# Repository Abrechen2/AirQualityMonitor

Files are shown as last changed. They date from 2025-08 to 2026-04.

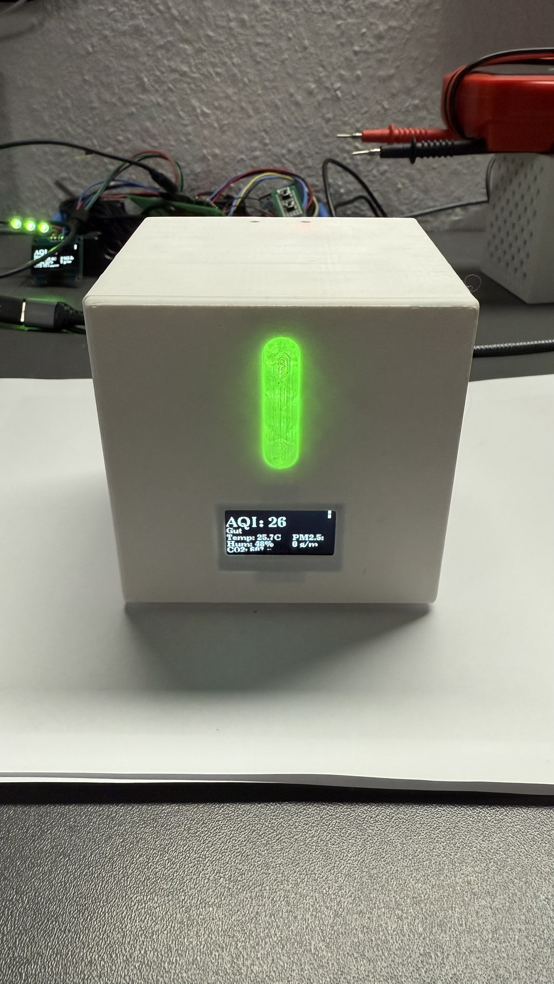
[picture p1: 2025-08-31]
Pictures/IMG_7561.JPEG

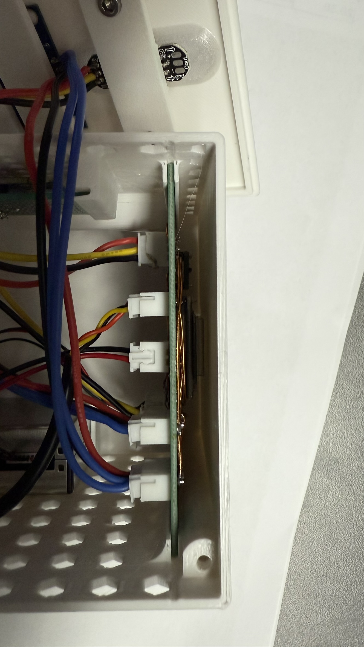
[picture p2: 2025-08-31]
Pictures/IMG_7567.JPEG

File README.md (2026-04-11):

# ESP32 Air Quality Monitor v1.5.6

   

Enclosure on Printables: <https://www.printables.com/model/1400485-esp32-air-quality-monitor-beluftetes-sensorgehause>

An advanced air-quality sensor based on the ESP32-WROOM-32 with three precise sensors for comprehensive environmental monitoring.

## Overview

This project implements a complete air-quality monitoring station with:
- **Real CO2 and TVOC values** (calculated with BME680/BME688 + BSEC)
- **Particulate matter measurement** (PM1.0, PM2.5, PM10)
- **Precise temperature measurement** via external DS18B20
- **MQTT Home Assistant integration** with automatic discovery (50+ entities)
- **Internal AQI calculation** (no external dependencies)
- **OLED display** for local visualization with 5 views
- **RGB LED status indicator** with smooth color transitions
- **Stealth mode** (display and LED off)

## Hardware Components

### Main Board
- **ESP32-WROOM-32** – microcontroller with Wi-Fi

### Sensors
| Sensor | Interface | Pin | Measurements |
|---|---|-----|---|
| **BME680/BME688** | I2C | SDA=21, SCL=22 | Temperature, humidity, pressure, gas resistance, IAQ, CO2eq, TVOC |
| **PMS5003** | UART | RX=16, TX=17 | PM1.0, PM2.5, PM10 µg/m³ |
| **DS18B20** | 1-Wire | GPIO27 | External temperature (±0.5 °C) |

### Output Devices
| Component | Interface | Pin |
|---|---|-----|
| **SH1106 OLED** (128×64) | I2C | SDA=21, SCL=22 |
| **WS2812B RGB LEDs** (3x) | GPIO | GPIO5 |
| **Button** | GPIO | GPIO33 |

## Key Features

### BSEC Algorithm Integration
- **Bosch BSEC library** (LP mode, 3s interval) for precise air-quality measurement
- **IAQ index** (Indoor Air Quality, 0-500)
- **CO2 equivalent** and **TVOC equivalent** calculation
- **Adaptive calibration** — state persisted to EEPROM every 6 hours

### MQTT Home Assistant Integration
- **Automatic device discovery** via MQTT discovery protocol
- **50+ sensor entities** including calculated values, alerts, and system status
- **Real-time updates** every 10 seconds
- **Wi-Fi auto-reconnect** with fallback modes
- **All calculations performed on ESP32** — no external dependencies
- **`has_entity_name: true`** + `object_id` for clean, predictable entity IDs

### OLED Display Views
| View | Content |
|---|---|
| OVERVIEW | AQI, level, temperature, humidity, CO2, PM2.5 |
| ENVIRONMENT | DS18B20 temp, BME68X temp/humidity/pressure |
| PARTICLES | PM1.0, PM2.5, PM10, AQI |
| GAS | IAQ, static IAQ, CO2, VOC, gas resistance, calibration |
| SYSTEM | Uptime, WiFi, IP, sensor count, firmware version |

### LED Status Colors
| Color | IAQ Range | Meaning |
|---|---|---|
| Green | 0-50 | Excellent |
| Yellow | 51-100 | Good |
| Orange | 101-150 | Lightly polluted |
| Red | 151-200 | Moderately polluted |
| Purple | 201-300 | Heavily polluted |
| Dark red | 300+ | Severely polluted |

## Installation

### 1. Hardware Connections
```
BME680/688:  SDA → GPIO21, SCL → GPIO22 (addr 0x76 or 0x77)
PMS5003:     RX → GPIO16, TX → GPIO17
DS18B20:     Data → GPIO27 (with 4.7kΩ pull-up)
OLED:        SDA → GPIO21, SCL → GPIO22 (addr 0x3C)
LEDs:        Data → GPIO5
Button:      GPIO33 (internal pull-up)
```

### 2. Required Libraries
- BSEC Software Library (Bosch Sensortec)
- PMS (PMS5003 sensor)
- DallasTemperature + OneWire (DS18B20)
- U8g2lib (OLED display)
- Adafruit NeoPixel (WS2812B LEDs)
- ArduinoJson
- PubSubClient (MQTT)
- ArduinoOTA

### 3. Arduino IDE Board Settings

These are the verified-working settings for the Arduino IDE (Tools menu) when
flashing an ESP32-WROOM-32 board with this firmware:

| Setting | Value |
|---|---|
| Board | ESP32 Dev Module |
| CPU Frequency | 240 MHz (WiFi/BT) |
| Core Debug Level | None |
| Erase All Flash Before Sketch Upload | Disabled |
| Events Run On | Core 1 |
| Flash Frequency | 80 MHz |
| Flash Mode | QIO |
| Flash Size | 4 MB (32 Mb) |
| JTAG Adapter | Disabled |
| Arduino Runs On | Core 1 |
| Partition Scheme | Default 4 MB with spiffs (1.2 MB APP / 1.5 MB SPIFFS) |
| PSRAM | Disabled |
| Upload Speed | 115200 |
| Zigbee Mode | Disabled |

> **Note on Partition Scheme:** The Arduino IDE GUI uses "Default" (1.2 MB APP
> slots). The `arduino-cli` OTA compile command in `CLAUDE.md` instead uses
> `min_spiffs` (1.9 MB APP slots) for more headroom as the firmware approaches
> 85 % of the flash (~1.1 MB). Both work, as long as the binary fits the OTA
> slot. For the initial USB flash, "Default" is fine.

### 4. Configuration

Create `secrets.h` from the template:
```bash
cp secrets_template.h secrets.h
```

Fill in credentials:
```cpp
#define WIFI_SSID       "YOUR_SSID"
#define WIFI_PASSWORD   "YOUR_PASSWORD"
#define MQTT_BROKER_HOST "192.168.1.100"
#define MQTT_BROKER_PORT 1883
#define HOSTNAME        "ENV-Room_Name"
#define MQTT_TOPIC      "ENV-Room_Name"   // must match HOSTNAME
#define OTA_PASSWORD    "yourpassword"
```

### 5. Compile and Flash

**Compile:**
```bash
ARDUINO_CLI="C:/Program Files/Arduino IDE/resources/app/lib/backend/resources/arduino-cli.exe"
"$ARDUINO_CLI" compile --fqbn esp32:esp32:esp32 \
  --build-property "build.partitions=min_spiffs" \
  --build-property "upload.maximum_size=1966080" \
  ./
```

**OTA Flash:**
```bash
ESPOTA="C:/Users/.../Arduino15/packages/esp32/hardware/esp32/3.3.7/tools/espota.py"
python "$ESPOTA" -i <DEVICE_IP> -p 3232 --auth="<OTA_PASSWORD>" \
  -f ./build/AirQualityMonitor.ino.bin
```

### 6. Calibration
- **BME680/688**: automatic BSEC calibration, accurate after 24-48h
- **State persistence** in EEPROM every 6 hours (survives power cycles)
- **CO2/TVOC accuracy** improves over 4-7 days of continuous operation

## MQTT Data Format

### Topics
| Topic | Description |
|---|---|
| `tele/<HOSTNAME>/state` | JSON payload, published every 10s |
| `tele/<HOSTNAME>/LWT` | `Online` / `Offline` (retained) |
| `homeassistant/<domain>/airqualitymonitor_<MAC>_<field>/config` | Discovery configs (retained) |

### Example State Payload
```json
{
  "temperature": 21.45,
  "humidity": 48.2,
  "pressure": 956.3,
  "iaq": 51,
  "static_iaq": 49,
  "iaq_accuracy": 3,
  "static_iaq_accuracy": 3,
  "co2": 621,
  "co2_accuracy": 3,
  "voc": 0.52,
  "voc_accuracy": 3,
  "gas_resistance": 183420,
  "bsec_calibrated": 1,
  "tvoc_ppb": 520,
  "tvoc_mgm3": 0.52,
  "pm1_0": 2,
  "pm2_5": 4,
  "pm10": 5,
  "dew_point": 10.1,
  "heat_index": 21.3,
  "absolute_humidity": 8.74,
  "comfort_index": 72,
  "external_temperature": 22.06,
  "aqi_index": 26.4,
  "aqi_category": 0,
  "pm2_5_aqi": 16,
  "pm10_aqi": 4,
  "iaq_aqi": 26,
  "sensor_bme68x_available": 1,
  "sensor_ds18b20_available": 1,
  "sensor_pms5003_available": 1,
  "sensors_available_count": 3,
  "sensor_reliable": 1,
  "bme68x_stable": 1,
  "bme68x_runin_complete": 1,
  "wifi_rssi": -62,
  "wifi_connected": 1,
  "mqtt_connected": 1,
  "stealth_mode": 0,
  "display_enabled": 1,
  "current_view": 0,
  "uptime": 14523,
  "free_heap": 148320,
  "ip_address": "192.168.200.78",
  "alert_aqi": 0,
  "alert_co2": 0,
  "alert_pm25": 0,
  "alert_tvoc": 0,
  "alert_humidity_low": 0,
  "alert_humidity_high": 0,
  "ventilation_needed": 0
}
```

### Home Assistant Entities
The device publishes discovery configs for all sensors automatically. Entity IDs follow the pattern `<domain>.env_<room>_<field>`.

**Environmental:**
`temperature`, `humidity`, `pressure`, `external_temperature`, `dew_point`, `heat_index`, `absolute_humidity`

**Air Quality (BSEC):**
`iaq`, `static_iaq`, `co2`, `voc`, `tvoc_mgm3`, `tvoc_ppb`, `gas_resistance`, accuracy indicators

**Particulate Matter:**
`pm1_0`, `pm2_5`, `pm10`, `pm2_5_aqi`, `pm10_aqi`

**AQI:**
`aqi_index`, `aqi_category`, `iaq_aqi`

**Comfort:**
`comfort_index`

**System:**
`uptime`, `free_heap`, `wifi_rssi`, `ip_address`, `current_view`, `sensors_available_count`

**Binary sensors:**
`sensor_bme68x_available`, `sensor_ds18b20_available`, `sensor_pms5003_available`, `bsec_calibrated`, `sensor_reliable`, `bme68x_stable`, `bme68x_runin_complete`, `wifi_connected`, `mqtt_connected`, `stealth_mode`, `display_enabled`

**Alerts:**
`alert_aqi`, `alert_co2`, `alert_pm25`, `alert_tvoc`, `alert_humidity_low`, `alert_humidity_high`, `ventilation_needed`

## Debugging

Serial debug output is controlled via `DEBUG_ENABLED` in `config.h`. Macros `DEBUG_INFO`, `DEBUG_WARN`, and `DEBUG_ERROR` provide formatted logs.

## Schematics & Layout

All KiCad files are in the [Schematics](Schematics) directory:
- [MainPCB-Schematic.pdf](Schematics/MainPCB-Schematic.pdf)
- [MainPCB-Layout.pdf](Schematics/MainPCB-Layout.pdf)

## Project Structure

```
AirQualityMonitor/
├── AirQualityMonitor.ino    # Main program
├── config.h                 # Hardware and timing configuration
├── secrets.h                # Credentials (not tracked in git)
├── secrets_template.h       # Template for secrets.h
├── SensorManager.h          # BME680/688, DS18B20, PMS5003 management
├── DisplayManager.h         # SH1106 OLED display and NeoPixel LEDs
├── ButtonHandler.h          # Button handling (view switch, stealth toggle)
├── LEDManager.h             # RGB LED control with smooth transitions
├── WiFiManager.h            # WiFi connection and reconnect logic
├── MQTTManager.h            # MQTT, Home Assistant discovery, data publish
├── Calculations.h           # AQI, comfort, dew point, heat index
├── TimeUtils.h              # Uptime helpers
├── DATENPUNKTE.md           # Detailed data point documentation (German)
├── CLAUDE.md                # Device inventory and OTA procedure
├── Schematics/              # KiCad project and PDFs
├── Printdata/               # STL and STEP files for enclosure
├── Pictures/                # Photos of the device
├── LICENSE                  # MIT license
└── README.md                # This file
```

## Troubleshooting

### Wi-Fi Connection Issues
- Check SSID and password in `secrets.h`
- 2.4 GHz only — 5 GHz not supported by ESP32-WROOM-32
- Verify signal strength (`wifi_rssi` entity in HA)

### Sensor Not Detected
- Check I2C connections (SDA=21, SCL=22)
- BME680/688: address must be 0x76 or 0x77 — system auto-detects both
- PMS5003: check UART wiring (RX/TX crossed), verify 5V power supply

### BSEC Calibration
| Phase | iaq_accuracy | Time |
|---|---|---|
| Warm-up | 0 | First 5 min |
| Initial calibration | 1 | 5-30 min |
| Calibrating | 2 | Up to 24h |
| Fully calibrated | 3 | After 4-7 days |

State is saved to EEPROM on first accuracy=2 and every 6h thereafter. After power cycle, calibration resumes quickly from saved state.

### OTA Flash Fails ("No response from device")
- Verify OTA password matches `OTA_PASSWORD` in `secrets.h`
- OTA port 3232 must be reachable from same VLAN
- Ensure `secrets.h` has the correct `HOSTNAME` for the target device before compiling
- See `CLAUDE.md` for the full sequential flash procedure

## Version History

| Version | Changes |
|---|---|
| **v1.5.6** | Stealth-mode button now shows a 3-2-1 countdown overlay while held and fires the toggle at 3s (no more "release-and-hope"); **critical fix**: `MQTTManager::init()` now re-reads hostname from `ConfigManager` after EEPROM load, so the same binary can be flashed to all boards without publishing under the wrong topic |
| **v1.5.5** | Sensible MQTT decimal precision; `has_entity_name` + `object_id` for clean HA entity IDs; all fields always published; `aqi_color_code` removed; firmware version on OLED |
| **v1.5.4** | MAC read after WiFi init (fixes discovery MAC mismatch); unique MQTT client ID per device |
| **v1.5.3** | BSEC state persistence to EEPROM; config EEPROM storage |
| **v1.5.2** | `expire_after` in MQTT discovery |
| **v1.5.1** | Fix MAC read before WiFi init returning `00ff00000000` |
| **v1.2.0** | MQTT Home Assistant integration; internal AQI calculation; removed Node-RED dependency |
| **v1.1.0** | Switch BSEC from ULP to LP mode for reliable CO2/VOC output |
| **v1.0.0** | Initial release |

## Contributing

1. Fork the repository
2. Create a feature branch
3. Commit your changes
4. Open a pull request

## Author

**Abrechen2**

## License

MIT License — see [LICENSE](LICENSE) for details.

---

*For detailed data point documentation see [DATENPUNKTE.md](DATENPUNKTE.md)*

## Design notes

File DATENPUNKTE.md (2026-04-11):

# Datenpunkte Erklaerung - ESP32 Luftqualitaetssensor

Diese Dokumentation erklaert alle vom Sensor erfassten und berechneten Datenpunkte,
deren Bedeutung, Quelle und Praezision im MQTT-State-Topic.

**MQTT State-Topic:** `tele/<HOSTNAME>/state`  
**Aktualisierungsintervall:** 10 Sekunden

---

## BME680 / BME688 Sensor (via BSEC LP-Mode)

### Basis-Umweltdaten

#### `temperature` — BME68X Temperatur
- **Typ:** float, 2 Dezimalstellen (°C)
- **Bereich:** -40 bis +85 °C
- **Quelle:** BSEC-kompensiert (Selbsterwärmungskorrektur integriert) + Software-Offset (`DEFAULT_TEMP_CORRECTION`)
- **Hinweis:** Für absolute Raumtemperatur DS18B20 verwenden (`external_temperature`)

#### `humidity` — Luftfeuchtigkeit
- **Typ:** float, 1 Dezimalstelle (% rH)
- **Bereich:** 0–100 %
- **Genauigkeit:** ±3 % rH (20–80 % rH)
- **Quelle:** BME68X via BSEC, mit Software-Offset (`DEFAULT_HUMIDITY_CORRECTION`)

#### `pressure` — Luftdruck
- **Typ:** float, 1 Dezimalstelle (hPa)
- **Bereich:** 300–1100 hPa
- **Genauigkeit:** ±1.0 hPa
- **Quelle:** BME68X Rohwert (Pa → hPa)

#### `gas_resistance` — Gaswiderstand
- **Typ:** integer (Ω)
- **Bereich:** ~10.000–500.000 Ω
- **Bedeutung:** Rohdaten des MOX-Gassensors. Niedriger Wert = schlechtere Luftqualität / mehr flüchtige organische Verbindungen
- **Hinweis:** Nicht direkt interpretierbar — BSEC verarbeitet diesen Wert intern

### BSEC-Algorithmus Outputs

#### `iaq` — Indoor Air Quality
- **Typ:** integer (0–500)
- **Quelle:** Proprietärer Bosch BSEC Algorithmus (Gaswiderstand, Temperatur, Luftfeuchtigkeit)
- **Kalibrierung:** Verbessert sich über 4–7 Tage; State wird alle 6h in EEPROM gespeichert

| Wert | Bewertung |
|---|---|
| 0–50 | Excellent |
| 51–100 | Good |
| 101–150 | Lightly Polluted |
| 151–200 | Moderately Polluted |
| 201–300 | Heavily Polluted |
| 300+ | Severely Polluted |

#### `static_iaq` — Static IAQ
- **Typ:** integer (0–500)
- **Unterschied zu IAQ:** Weniger empfindlich gegenüber kurzfristigen Änderungen, besser für Langzeittrend

#### `iaq_accuracy` / `static_iaq_accuracy` — Kalibrierungsfortschritt
- **Typ:** integer (0–3)

| Wert | Bedeutung |
|---|---|
| 0 | Sensor läuft ein (erste ~5 min) |
| 1 | Unsichere Kalibrierung |
| 2 | Kalibrierung aktiv (~24h) |
| 3 | Vollständig kalibriert (4–7 Tage) |

#### `co2` — CO₂-Äquivalent
- **Typ:** integer (ppm)
- **Bereich:** 400–40.000 ppm
- **Wichtig:** Nicht direkt gemessen — BSEC-Schätzung auf Basis des Gaswiderstandsverlaufs

| Wert | Bewertung |
|---|---|
| 400–1000 ppm | Gut |
| 1000–2000 ppm | Akzeptabel |
| 2000–5000 ppm | Schlecht |
| >5000 ppm | Gesundheitsschädlich |

#### `co2_accuracy` — CO₂ Genauigkeitsstatus
- **Typ:** integer (0–3), wie `iaq_accuracy`

#### `voc` / `tvoc_mgm3` — TVOC-Äquivalent
- **Typ:** float, 2 Dezimalstellen (mg/m³)
- **Bereich:** 0–60 mg/m³
- **Vollname:** Total Volatile Organic Compounds
- **Quelle:** BSEC-Algorithmus (Gaswiderstandsverlauf)
- **Hinweis:** Relative Werte, keine absoluten Konzentrationen einzelner Substanzen

| Wert | Bewertung |
|---|---|
| 0–0.3 mg/m³ | Excellent |
| 0.3–1.0 mg/m³ | Good |
| 1.0–3.0 mg/m³ | Moderate |
| 3.0–25 mg/m³ | Poor |
| >25 mg/m³ | Unhealthy |

#### `tvoc_ppb` — TVOC in ppb
- **Typ:** integer (ppb)
- **Berechnung:** `voc_mgm3 * 1000`
- **Verwendung:** Für HA-Karten die ppb bevorzugen

#### `voc_accuracy` — VOC Genauigkeitsstatus
- **Typ:** integer (0–3)

#### `bsec_calibrated` — Kalibrierungsstatus
- **Typ:** binary (0/1)
- **Wert 1:** `iaqAccuracy >= 1`

---

## DS18B20 Temperatursensor

#### `external_temperature` — Externe Temperatur
- **Typ:** float, 2 Dezimalstellen (°C)
- **Bereich:** -55 bis +125 °C
- **Genauigkeit:** ±0.5 °C (-10 bis +85 °C)
- **Auflösung:** 12-bit (0.0625 °C)
- **Verwendung:** Primäre Raumtemperatur (kein Selbsterwärmungseffekt)
- **Leseintervall:** 10 Sekunden

---

## PMS5003 Feinstaubsensor

Messprinzip: Laser-Streulicht — Partikel werden gezählt und in Massenkonzentration umgerechnet.

#### `pm1_0` — PM1.0
- **Typ:** integer (µg/m³)
- **Definition:** Partikel mit Durchmesser ≤ 1.0 µm
- **Gesundheit:** Dringen bis in Lungenbläschen vor

#### `pm2_5` — PM2.5
- **Typ:** integer (µg/m³)
- **Definition:** Partikel ≤ 2.5 µm

| WHO-Grenzwert | Wert |
|---|---|
| Jahresmittel | 5 µg/m³ |
| 24h-Mittel | 15 µg/m³ |

#### `pm10` — PM10
- **Typ:** integer (µg/m³)
- **Definition:** Partikel ≤ 10 µm

| WHO-Grenzwert | Wert |
|---|---|
| Jahresmittel | 15 µg/m³ |
| 24h-Mittel | 45 µg/m³ |

---

## Berechnete Komfortwerte (intern auf ESP32)

#### `dew_point` — Taupunkt
- **Typ:** float, 1 Dezimalstelle (°C)
- **Berechnung:** Magnus-Formel aus Temperatur + Luftfeuchtigkeit
- **Bedeutung:** Unter diesem Wert kondensiert Wasserdampf

#### `heat_index` — Gefühlte Temperatur
- **Typ:** float, 1 Dezimalstelle (°C)
- **Berechnung:** Rothfusz-Regression (Temperatur + Luftfeuchtigkeit)
- **Bedeutung:** Relevanter über 27 °C bei hoher Luftfeuchtigkeit

#### `absolute_humidity` — Absolute Luftfeuchtigkeit
- **Typ:** float, 2 Dezimalstellen (g/m³)
- **Berechnung:** Aus Temperatur und relativer Luftfeuchtigkeit
- **Verwendung:** Lüftungssteuerung (innen vs. außen vergleichen)

#### `comfort_index` — Komfortindex
- **Typ:** integer (0–100)
- **Berechnung:** Kombiniert Temperatur, Luftfeuchtigkeit und Heat Index
- **100:** Optimaler Komfort; niedrigere Werte = zu warm/kalt/trocken/feucht

---

## AQI-Werte (intern berechnet)

#### `aqi_index` — Gesamt-AQI
- **Typ:** float, 1 Dezimalstelle
- **Berechnung:** Gewichtete Kombination aus PM2.5-AQI, PM10-AQI, IAQ-AQI
- **Grundlage:** US-EPA AQI Skala

#### `aqi_category` — AQI Kategorie
- **Typ:** integer (0–5)

| Wert | Bedeutung |
|---|---|
| 0 | Good (0–50) |
| 1 | Moderate (51–100) |
| 2 | Unhealthy for Sensitive Groups (101–150) |
| 3 | Unhealthy (151–200) |
| 4 | Very Unhealthy (201–300) |
| 5 | Hazardous (300+) |

#### `pm2_5_aqi` — PM2.5 AQI
- **Typ:** integer
- **Berechnung:** US-EPA Breakpoint-Tabelle für PM2.5

#### `pm10_aqi` — PM10 AQI
- **Typ:** integer
- **Berechnung:** US-EPA Breakpoint-Tabelle für PM10

#### `iaq_aqi` — IAQ → AQI Umrechnung
- **Typ:** integer
- **Berechnung:** Lineares Mapping von BSEC IAQ (0–500) auf AQI Skala

---

## Alert-Flags (Binary Sensors)

Alle Flags: integer 0 oder 1

| Feld | Auslöser |
|---|---|
| `alert_aqi` | AQI > 100 (Unhealthy for Sensitive Groups) |
| `alert_co2` | CO₂ > 1500 ppm |
| `alert_pm25` | PM2.5 > 35 µg/m³ |
| `alert_tvoc` | TVOC > 1.0 mg/m³ |
| `alert_humidity_low` | Luftfeuchtigkeit < 30 % |
| `alert_humidity_high` | Luftfeuchtigkeit > 70 % |
| `ventilation_needed` | Kombination aus CO₂ oder TVOC-Alert |

---

## Sensor-Verfügbarkeit (Binary Sensors)

| Feld | Bedeutung |
|---|---|
| `sensor_bme68x_available` | BME680/688 initialisiert und liefert Daten |
| `sensor_ds18b20_available` | DS18B20 gefunden und liest Temperatur |
| `sensor_pms5003_available` | PMS5003 kommuniziert (0 nach 5 Fehler in Folge) |
| `bsec_calibrated` | iaqAccuracy >= 1 |
| `sensor_reliable` | Mindestens ein Sensor liefert valide Daten |
| `bme68x_stable` | iaqAccuracy >= 2 |
| `bme68x_runin_complete` | iaqAccuracy >= 3 (vollständig kalibriert) |
| `sensors_available_count` | Anzahl aktiver Sensoren (0–3) |

**Wichtig:** Alle Sensor-Felder werden immer publiziert, auch wenn der Sensor offline ist (Wert = 0). `sensor_<x>_available = 0` zeigt die Nichtverfügbarkeit an.

---

## System-Status

| Feld | Typ | Bedeutung |
|---|-----|---|
| `uptime` | integer (s) | Sekunden seit letztem Reboot |
| `free_heap` | integer (Bytes) | Freier Heap-Speicher |
| `wifi_rssi` | integer (dBm) | WLAN-Signalstärke |
| `wifi_connected` | binary | WLAN verbunden |
| `mqtt_connected` | binary | MQTT-Broker verbunden |
| `ip_address` | string | Aktuelle IP-Adresse |
| `stealth_mode` | binary | Stealth-Modus aktiv (Display + LEDs aus) |
| `display_enabled` | binary | OLED erkannt und aktiv |
| `current_view` | integer (0–4) | Aktuell angezeigte View (0=Overview … 4=System) |

---

## BSEC Konfiguration

**Modus:** LP (Low Power) — 3-Sekunden-Messintervall  
**Vorteil:** Zuverlässige CO₂/VOC-Ausgaben (ULP liefert hier Nullwerte)  
**State-Speicherung:** alle 6h in EEPROM (Adresse 0); zusätzlich sofort beim Erreichen von iaqAccuracy=2

Aktive BSEC-Outputs:
```
BSEC_OUTPUT_IAQ
BSEC_OUTPUT_STATIC_IAQ
BSEC_OUTPUT_CO2_EQUIVALENT
BSEC_OUTPUT_BREATH_VOC_EQUIVALENT
BSEC_OUTPUT_SENSOR_HEAT_COMPENSATED_TEMPERATURE
BSEC_OUTPUT_SENSOR_HEAT_COMPENSATED_HUMIDITY
BSEC_OUTPUT_RAW_PRESSURE
BSEC_OUTPUT_RAW_GAS
BSEC_OUTPUT_STABILIZATION_STATUS
BSEC_OUTPUT_RUN_IN_STATUS
BSEC_OUTPUT_GAS_PERCENTAGE
```

---

## Wichtige Hinweise

- **CO₂ und TVOC sind Schätzwerte** — kein direkter Gassensor, nur BSEC-Algorithmus
- **PMS5003** ist unzuverlässig bei Luftfeuchtigkeit > 85 %
- **BME680 Selbsterwärmung** wird durch BSEC und Software-Offset (`DEFAULT_TEMP_CORRECTION = -3.5 °C`) kompensiert; DS18B20 ist die Referenztemperatur
- **Erste 24–48h nach Neuinstallation:** iaqAccuracy ≤ 1, CO₂/VOC-Werte noch unzuverlässig

---

*Dokumentiert für Firmware v1.5.5*

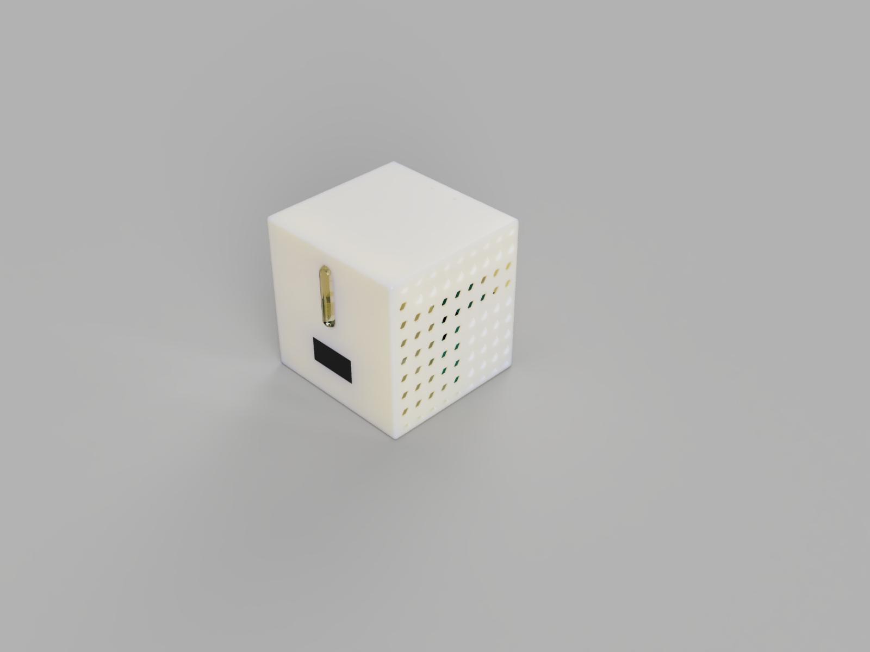
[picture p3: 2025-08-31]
Pictures/AirQualityMonitor.jpg

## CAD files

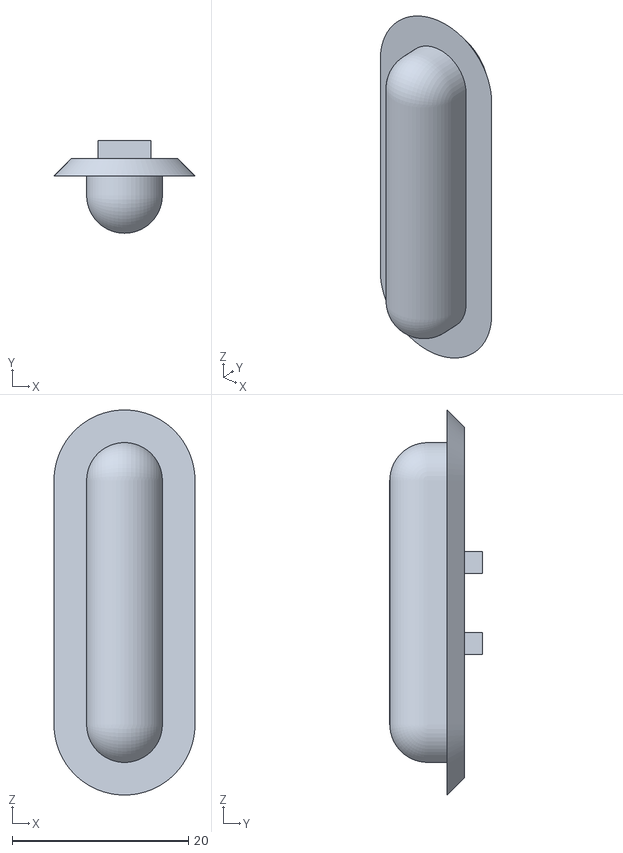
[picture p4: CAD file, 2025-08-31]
Printdata/Diffusor.stl
16.0 x 10.5 x 43.7

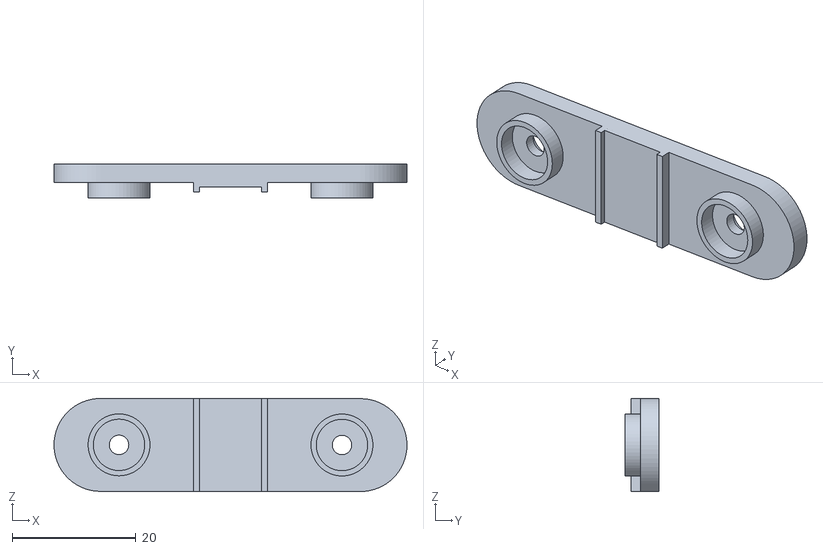
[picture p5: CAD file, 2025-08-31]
Printdata/LEDHalter.stl
57.0 x 5.50 x 15.0

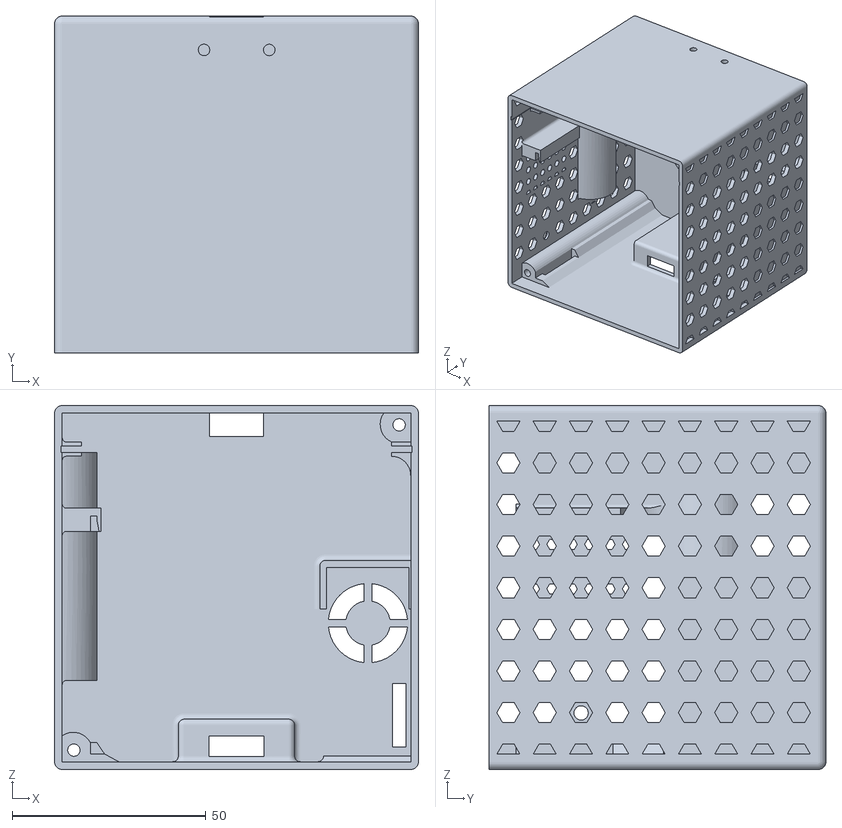
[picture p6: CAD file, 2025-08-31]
Printdata/Gehäuse.stl
94.0 x 87.0 x 94.0

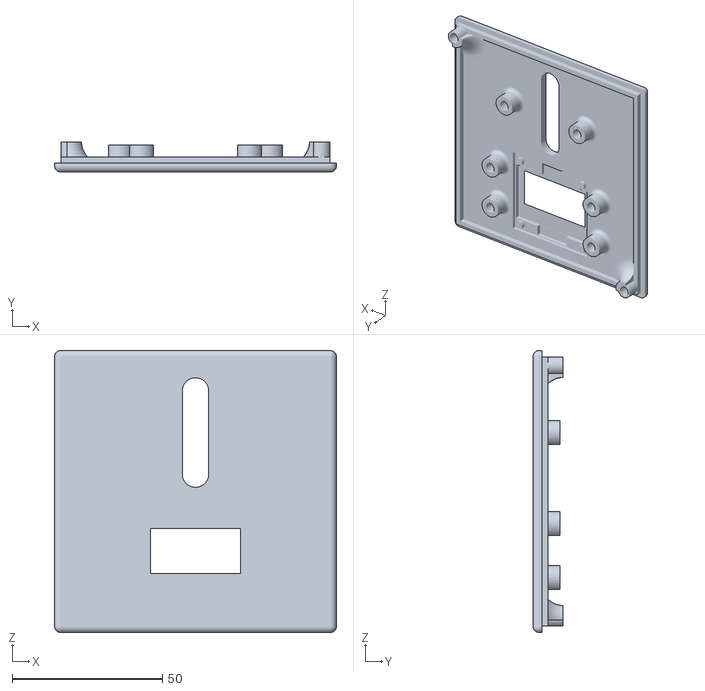
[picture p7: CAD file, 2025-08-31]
Printdata/Deckel.stl
94.0 x 10.0 x 94.0

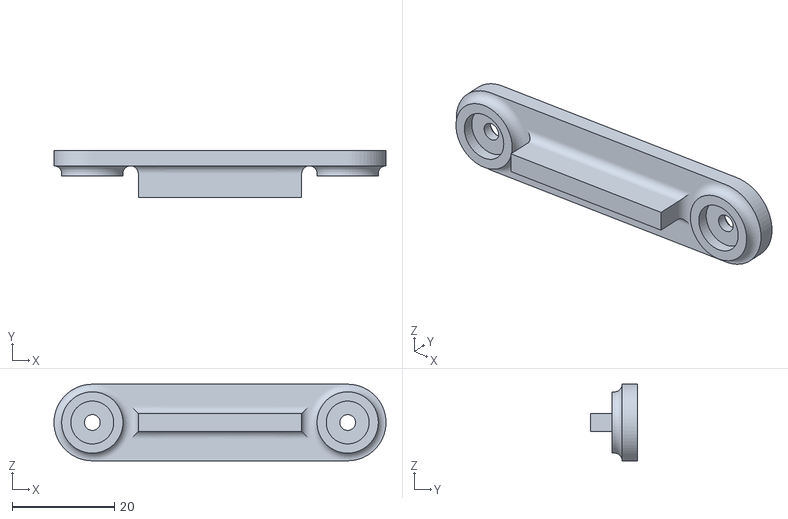
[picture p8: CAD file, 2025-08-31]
Printdata/OledHalter.stl
65.0 x 9.17 x 15.0

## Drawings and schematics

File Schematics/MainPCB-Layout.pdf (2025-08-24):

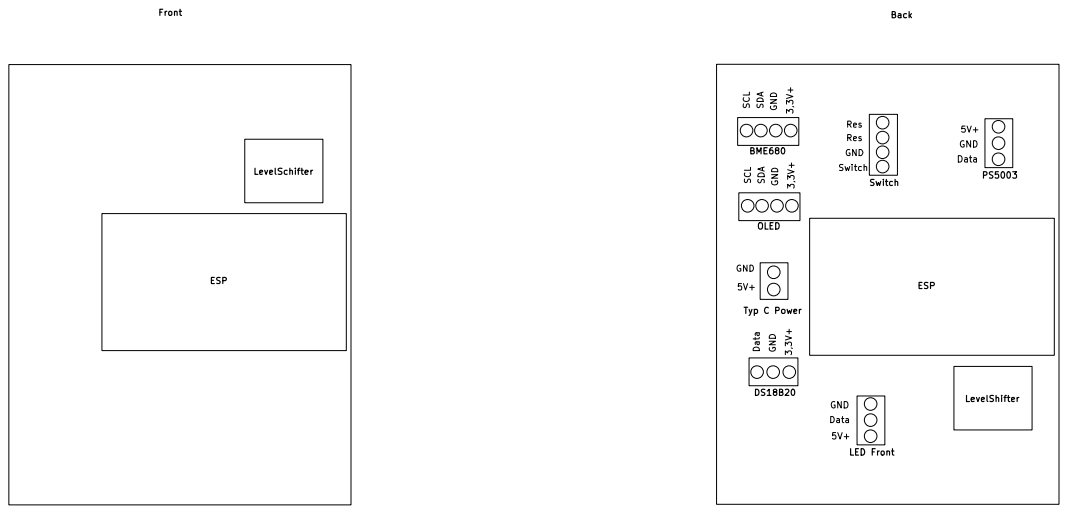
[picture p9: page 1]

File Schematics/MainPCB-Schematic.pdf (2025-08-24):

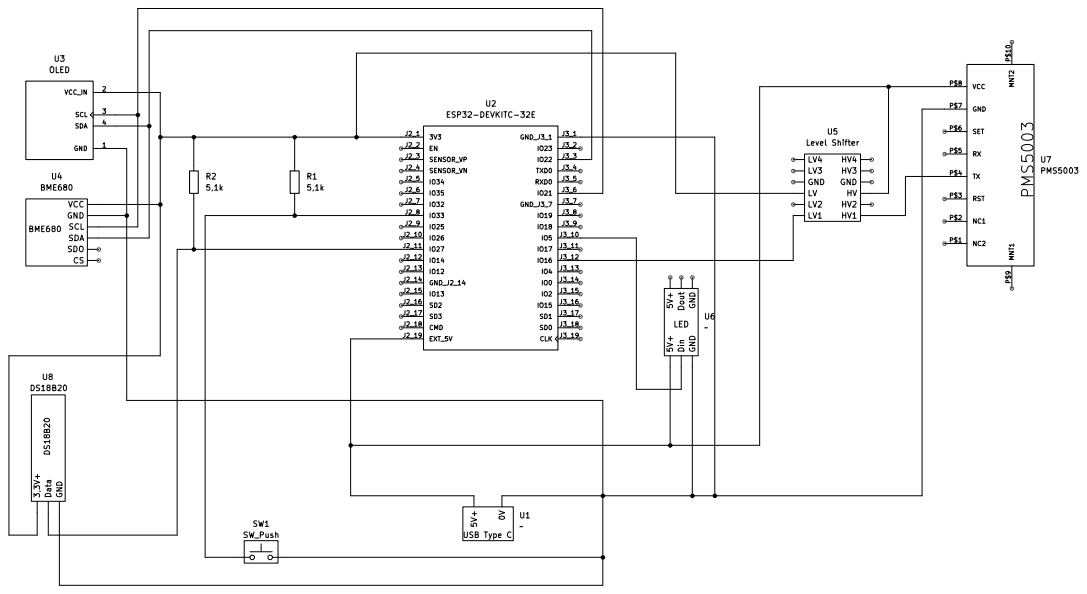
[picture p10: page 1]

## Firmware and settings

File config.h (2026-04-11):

#ifndef CONFIG_H
#define CONFIG_H

// ===== FIRMWARE VERSION =====
#define FIRMWARE_VERSION "1.5.6"

// ===== HARDWARE CONFIGURATION =====
#define LED_PIN 5
#define NUM_LEDS 3
#define LED_BRIGHTNESS_NORMAL 20
#define LED_BRIGHTNESS_STEALTH 1

// Display
#define SCREEN_WIDTH 128
#define SCREEN_HEIGHT 64
#define DISPLAY_SCL 22
#define DISPLAY_SDA 21
#define DISPLAY_CONTRAST_NORMAL 255
#define DISPLAY_CONTRAST_STEALTH 0

// Sensors
#define PMS_RX_PIN 16
#define PMS_TX_PIN 17
#define DS18B20_PIN 27  // GPIO27 (original configuration retained)

// BME680/BME688 I2C addresses (standard: 0x76 with SDO low, 0x77 with SDO high)
#ifndef BME68X_I2C_ADDR_LOW
#define BME68X_I2C_ADDR_LOW 0x76
#endif
#ifndef BME68X_I2C_ADDR_HIGH
#define BME68X_I2C_ADDR_HIGH 0x77
#endif

// Button - only use select
#define BUTTON_SELECT_PIN 33
#define BUTTON_DEBOUNCE_MS 50
#define BUTTON_LONG_PRESS_MS 3000             // 3 seconds to trigger stealth toggle
#define BUTTON_COUNTDOWN_SHOW_AFTER_MS 300    // Start showing countdown after 300ms hold

// ===== TIMING CONFIGURATION =====
#define DATA_SEND_INTERVAL 10000       // 10 seconds
#define SENSOR_READ_INTERVAL 3000      // 3 seconds (BSEC ULP mode compromise)
#define WIFI_CONNECT_TIMEOUT 8000      // 8 seconds
#define STEALTH_TEMP_ON_MS 20000       // 20 seconds temporary activation
#define LED_TRANSITION_STEPS 20        // Number of steps for smooth color transition
#define LED_TRANSITION_INTERVAL_MS 50  // Time between transition steps (ms)

// ===== MQTT CONFIGURATION =====
#define MQTT_PUBLISH_INTERVAL 10000           // 10 seconds (synchronized with DATA_SEND_INTERVAL)
#define MQTT_RECONNECT_INTERVAL 5000          // 5 seconds between reconnect attempts
#define MQTT_MAX_PACKET_SIZE 2048             // Maximum MQTT packet size (bytes)
#define DISCOVERY_REPUBLISH_INTERVAL 3600000  // 60 minutes (ms) - republish discovery config periodically

// ===== SENSOR CONFIGURATION =====
#define DEFAULT_TEMP_CORRECTION -3.5
#define DEFAULT_HUMIDITY_CORRECTION 0.0

// BSEC configuration
#define BSEC_STATE_SAVE_INTERVAL 21600000  // 6 hours in ms
#define BSEC_BASELINE_EEPROM_ADDR 0

// Config storage in EEPROM (after BSEC state)
#define CONFIG_EEPROM_ADDR 512  // Start address for config storage
#define CONFIG_EEPROM_SIZE 256  // Size allocated for config (max 512 total)

// ===== VALIDATION CONSTANTS =====
// Sensor value ranges for plausibility checks
#define TEMP_MIN -40.0f       // Minimum valid temperature (°C)
#define TEMP_MAX 85.0f        // Maximum valid temperature (°C)
#define HUMIDITY_MIN 0.0f     // Minimum valid humidity (%)
#define HUMIDITY_MAX 100.0f   // Maximum valid humidity (%)
#define PRESSURE_MIN 300.0f   // Minimum valid pressure (hPa)
#define PRESSURE_MAX 1100.0f  // Maximum valid pressure (hPa)
#define IAQ_MIN 0.0f          // Minimum valid IAQ
#define IAQ_MAX 500.0f        // Maximum valid IAQ
#define CO2_MIN 400.0f        // Minimum valid CO2 (ppm)
#define CO2_MAX 40000.0f      // Maximum valid CO2 (ppm)
#define VOC_MIN 0.0f          // Minimum valid VOC (mg/m³)
#define VOC_MAX 60.0f         // Maximum valid VOC (mg/m³)
#define PM_MIN 0              // Minimum valid PM value (µg/m³)
#define PM_MAX 1000           // Maximum valid PM value (µg/m³)

// HTTP/Network constants
#define HTTP_MAX_RESPONSE_SIZE 1024  // Maximum HTTP response size (bytes)
#define HTTP_TIMEOUT_MS 5000         // HTTP request timeout (ms)
#define HTTP_AQI_TIMEOUT_MS 3000     // AQI request timeout (ms)
#define JSON_MAX_SIZE 256            // Maximum JSON document size (bytes)

// PMS5003 constants
#define PMS_READ_TIMEOUT_MS 1000  // PMS5003 read timeout (ms)
#define PMS_WAKE_TIME_MS 2000     // PMS5003 wake time (ms)
#define PMS_RETRY_COUNT 2         // Maximum retry attempts for PMS5003

// DS18B20 constants
#define DS18B20_CONVERSION_TIME_MS 750  // DS18B20 conversion time (ms)
#define DS18B20_READ_INTERVAL_MS 10000  // DS18B20 read interval (ms)

// Type conversion limits (for overflow protection)
#define INT16_TEMP_MAX 3276        // Max temp * 100 for int16_t (32.76°C)
#define INT16_TEMP_MIN -3276       // Min temp * 100 for int16_t (-32.76°C)
#define UINT16_HUMIDITY_MAX 10000  // Max humidity * 100 for uint16_t (100.00%)
#define UINT16_PRESSURE_MAX 6553   // Max pressure * 10 for uint16_t (655.3 hPa)
#define UINT16_IAQ_MAX 5000        // Max IAQ * 10 for uint16_t (500.0)
#define UINT16_VOC_MAX 6000        // Max VOC * 100 for uint16_t (60.00 mg/m³)

// ===== DISPLAY VIEWS =====
enum DisplayView {
  VIEW_OVERVIEW = 0,
  VIEW_ENVIRONMENT,
  VIEW_PARTICLES,
  VIEW_GAS,  // Gas sensors
  VIEW_SYSTEM,
  VIEW_COUNT
};

// ===== STEALTH MODE =====
enum StealthMode {
  STEALTH_OFF = 0,
  STEALTH_ON,
  STEALTH_TEMP_ON  // Temporarily enabled
};

// ===== WIFI MANAGER CONFIGURATION =====
// Uncomment to use WiFiManager library for credential management
// This provides a web portal for WiFi configuration (more secure than hardcoded credentials)
// Requires: WiFiManager library (https://github.com/tzapu/WiFiManager)
// #define USE_WIFI_MANAGER 1

// ===== ERROR CODES =====
enum ErrorCode {
  ERROR_NONE = 0,
  ERROR_SENSOR_INIT_FAILED = 1,
  ERROR_SENSOR_READ_FAILED = 2,
  ERROR_WIFI_CONNECT_FAILED = 3,
  ERROR_MQTT_CONNECT_FAILED = 4,
  ERROR_HTTP_REQUEST_FAILED = 5,
  ERROR_JSON_PARSE_FAILED = 6,
  ERROR_EEPROM_FAILED = 7,
  ERROR_INVALID_DATA = 8,
  ERROR_OVERFLOW = 9
};

// ===== DEBUG CONFIGURATION =====
#define DEBUG_ENABLED 1

#if DEBUG_ENABLED
// Basic debug macros
#define DEBUG_PRINT(x) Serial.print(x)
#define DEBUG_PRINTLN(x) Serial.println(x)
#define DEBUG_PRINTF(fmt, ...) Serial.printf(fmt, ##__VA_ARGS__)
// Structured logging helpers for clearer output
#define DEBUG_INFO(fmt, ...) Serial.printf("[INFO] " fmt "\n", ##__VA_ARGS__)
#define DEBUG_WARN(fmt, ...) Serial.printf("[WARN] " fmt "\n", ##__VA_ARGS__)
#define DEBUG_ERROR(fmt, ...) Serial.printf("[ERROR] " fmt "\n", ##__VA_ARGS__)
#else
#define DEBUG_PRINT(x)
#define DEBUG_PRINTLN(x)
#define DEBUG_PRINTF(fmt, ...)
#define DEBUG_INFO(fmt, ...)
#define DEBUG_WARN(fmt, ...)
#define DEBUG_ERROR(fmt, ...)
#endif

#endif

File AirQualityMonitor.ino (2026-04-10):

// ===== AIR QUALITY MONITOR V1.5.4 - INTERNAL CALCULATIONS =====
// Advanced version with BSEC LP Mode, Stealth Control, CO2/VOC, Internal Calculations
// Author: Dennis Wittke
// Version: 1.5.4 - Fix MQTT discovery MAC mismatch, BSEC state handling, PMS5003 failure tracking
// Date: 2025

#include <Arduino.h>
#include "bsec.h"
#include <Wire.h>
#include <WiFi.h>
#include <PubSubClient.h>
#include <U8g2lib.h>
#include "PMS.h"
#include <OneWire.h>
#include <DallasTemperature.h>
#include <Adafruit_NeoPixel.h>
#include <ArduinoJson.h>
#include <EEPROM.h>
#include <ArduinoOTA.h>

// Project includes
#include "config.h"
#include "secrets.h"
#include "ConfigManager.h"
#include "SensorManager.h"
#include "DisplayManager.h"
#include "ButtonHandler.h"
#include "LEDManager.h"
#include "WiFiManager.h"
#include "Calculations.h"
#include "MQTTManager.h"

// ===== HARDWARE OBJECTS =====
Adafruit_NeoPixel strip = Adafruit_NeoPixel(NUM_LEDS, LED_PIN, NEO_GRB + NEO_KHZ800);
Bsec iaqSensor;
PMS pms(Serial1);
U8G2_SH1106_128X64_NONAME_F_HW_I2C u8g2(U8G2_R0, U8X8_PIN_NONE, DISPLAY_SCL, DISPLAY_SDA);

// ===== SYSTEM OBJECTS =====
ConfigManager configManager;
SensorManager sensorManager(iaqSensor, pms);
DisplayManager displayManager(u8g2, strip);
ButtonHandler buttonHandler(displayManager);
LEDManager ledManager(strip, displayManager);
WiFiManager wifiManager(&configManager);
MQTTManager mqttManager(&configManager);

// ===== GLOBAL VARIABLES =====
bool wifiConnected = false;
float calculatedAQI = 50.0;
const char* aqiLevel = "Good";
uint32_t aqiColorCode = 0x00FF00; // Green

void setup() {
  Serial.begin(115200);
  delay(1000);
  
  DEBUG_INFO("=== Air Quality Monitor starting ===");
  
  // Print ESP32 Core version information
  #if defined(ESP32)
    DEBUG_INFO("ESP32 Arduino Core Version: %s", ESP.getSdkVersion());
    DEBUG_INFO("ESP32 Chip Model: %s", ESP.getChipModel());
    DEBUG_INFO("ESP32 Chip Revision: %d", ESP.getChipRevision());
    DEBUG_INFO("ESP32 CPU Frequency: %d MHz", ESP.getCpuFreqMHz());
  #endif
 
  // Initialize hardware
  Wire.begin(DISPLAY_SDA, DISPLAY_SCL);
  Wire.setClock(100000);
  delay(100);
  
  Serial1.begin(9600, SERIAL_8N1, PMS_RX_PIN, PMS_TX_PIN);
  delay(100);

  // Initialize components
  displayManager.init();
  ledManager.init();
  buttonHandler.init();
  
  // Show startup messages
  displayManager.showMessage("System starting...");

  // Initialize sensors (also initializes EEPROM)
  displayManager.showMessage("Initializing sensors...");
  bool sensorsOK = sensorManager.init();
  
  if (sensorsOK) {
    displayManager.showMessage("Sensors OK!", 1000);
  } else {
    displayManager.showMessage("Sensor warning!", 5000);
  }

  // Initialize config manager (after EEPROM is initialized)
  if (!configManager.init()) {
    DEBUG_ERROR("ConfigManager initialization failed");
  }

  // Connect to WiFi
  displayManager.showMessage("Connecting WiFi...");
  wifiConnected = wifiManager.connect();

  if (wifiConnected) {
    displayManager.showMessage("WiFi connected!", 1000);
    String ip = wifiManager.getIPAddress();
    displayManager.showMessage("IP: " + ip, 2000);
    DEBUG_INFO("WiFi connected successfully");

    // Initialize MQTT
    mqttManager.init();
    if (mqttManager.connect()) {
      DEBUG_INFO("MQTT connected successfully");
    } else {
      DEBUG_WARN("MQTT connection failed - will retry in loop");
    }
    
    // Initialize Arduino OTA
    initOTA();
  } else {
    displayManager.showMessage("Offline mode", 5000);
    DEBUG_WARN("WiFi connection failed - offline mode");
  }

  displayManager.showMessage("System ready!", 1000);
  DEBUG_INFO("Setup completed");
}

void loop() {
  static unsigned long lastDebugTime = 0;
  static uint8_t loopDebugCount = 0;

  // Update system components
  buttonHandler.update();

  // Read sensors
  if (sensorManager.update()) {
    SensorData data = sensorManager.getData();

    // Enhanced debug output for sensor data
    if (loopDebugCount < 10 || (millis() - lastDebugTime > 30000)) {
      DEBUG_INFO("=== Sensor Data Update ===");
      if (data.bme68xAvailable) {
        DEBUG_INFO("BME68X - Temp: %.1f°C, Hum: %.1f%%, Press: %.1f hPa, Gas: %.0f Ohm",
                   data.temperature, data.humidity, data.pressure, data.gasResistance);
        DEBUG_INFO("BSEC - IAQ: %.0f (acc:%d), CO2: %.0f ppm (acc:%d), VOC: %.1f mg/m3 (acc:%d)",
                   data.iaq, data.iaqAccuracy,
                   data.co2Equivalent, data.co2Accuracy,
                   data.breathVocEquivalent, data.breathVocAccuracy);
      } else {
        DEBUG_WARN("BME68X not available!");
      }
      if (data.pms5003Available) {
        DEBUG_INFO("PMS5003 - PM1.0: %d, PM2.5: %d, PM10: %d µg/m³",
                   data.pm1_0, data.pm2_5, data.pm10);
      }
      lastDebugTime = millis();
      loopDebugCount++;
    }

    // Calculate AQI internally using Calculations.h
    calculatedAQI = calculateCombinedAQI(data);
    aqiLevel = getAQILevelString(calculatedAQI);
    aqiColorCode = calculateAQIColor(calculatedAQI);

    // Update display and LEDs
    displayManager.updateDisplay(data, calculatedAQI, String(aqiLevel), wifiConnected);
    ledManager.updateLEDsWithTransition(aqiColorCode);
    
    // Publish data to MQTT with all calculated values
    if (wifiConnected) {
      mqttManager.update();
      mqttManager.publishData(data, calculatedAQI, String(aqiLevel), wifiConnected, displayManager);
    }
  }

  // Update MQTT connection (even when no sensor data update)
  if (wifiConnected) {
    mqttManager.update();
    
    // Handle Arduino OTA updates
    ArduinoOTA.handle();
  }

  // Check WiFi connection - always try to reconnect if not connected
  if (!wifiManager.isConnected()) {
    static unsigned long lastWifiReconnect = 0;
    unsigned long now = millis();
    
    // Try to reconnect every 30 seconds
    if (now - lastWifiReconnect >= 30000) {
      lastWifiReconnect = now;
      DEBUG_WARN("WiFi not connected - attempting reconnection");
      bool newConnection = wifiManager.connect();
      
      if (newConnection) {
        wifiConnected = true;
        DEBUG_INFO("WiFi reconnected successfully");
        // Reinitialize MQTT and OTA after WiFi reconnection
        mqttManager.init();
        if (mqttManager.connect()) {
          DEBUG_INFO("MQTT reconnected after WiFi reconnection");
        }
        initOTA();
      } else {
        wifiConnected = false;
        DEBUG_WARN("WiFi reconnection failed - will retry in 30 seconds");
      }
    }
  } else if (!wifiConnected) {
    // WiFi has reconnected automatically (via setAutoReconnect)
    wifiConnected = true;
    DEBUG_INFO("WiFi auto-reconnected - reinitializing MQTT and OTA");
    mqttManager.init();
    if (mqttManager.connect()) {
      DEBUG_INFO("MQTT reconnected after WiFi auto-reconnection");
    }
    initOTA();
  }
  
  // Always update LED transitions (even when no sensor update)
  ledManager.updateLEDsWithTransition(aqiColorCode);
}

// ===== ARDUINO OTA FUNCTIONS =====
void initOTA() {
  DEBUG_INFO("Initializing Arduino OTA...");
  
  // Set hostname - use configured hostname if available, otherwise fallback to MAC-based
  String hostname;
  if (strlen(configManager.getHostname()) > 0) {
    hostname = String(configManager.getHostname());
  } else {
    hostname = "AirQualityMonitor_" + WiFi.macAddress();
    hostname.replace(":", "");
  }
  ArduinoOTA.setHostname(hostname.c_str());
  
  // Set password if configured
  #ifdef OTA_PASSWORD
    ArduinoOTA.setPassword(OTA_PASSWORD);
    DEBUG_INFO("OTA password protection enabled");
  #else
    DEBUG_WARN("OTA password not set - updates are unprotected!");
  #endif
  
  // OTA callbacks
  ArduinoOTA.onStart([]() {
    String type;
    if (ArduinoOTA.getCommand() == U_FLASH) {
      type = "sketch";
    } else { // U_SPIFFS
      type = "filesystem";
    }
    DEBUG_INFO("Start updating %s", type.c_str());
  });
  
  ArduinoOTA.onEnd([]() {
    DEBUG_INFO("\nEnd");
  });
  
  ArduinoOTA.onProgress([](unsigned int progress, unsigned int total) {
    DEBUG_INFO("Progress: %u%%\r", (progress / (total / 100)));
  });
  
  ArduinoOTA.onError([](ota_error_t error) {
    DEBUG_ERROR("Error[%u]: ", error);
    if (error == OTA_AUTH_ERROR) {
      DEBUG_ERROR("Auth Failed");
    } else if (error == OTA_BEGIN_ERROR) {
      DEBUG_ERROR("Begin Failed");
    } else if (error == OTA_CONNECT_ERROR) {
      DEBUG_ERROR("Connect Failed");
    } else if (error == OTA_RECEIVE_ERROR) {
      DEBUG_ERROR("Receive Failed");
    } else if (error == OTA_END_ERROR) {
      DEBUG_ERROR("End Failed");
    }
  });
  
  ArduinoOTA.begin();
  DEBUG_INFO("Arduino OTA ready - Hostname: %s", hostname.c_str());
}

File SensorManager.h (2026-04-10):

#ifndef SENSOR_MANAGER_H
#define SENSOR_MANAGER_H

#include <Arduino.h>
#include <Wire.h>
#include "bsec.h"
#include "PMS.h"
#include <OneWire.h>
#include <DallasTemperature.h>
#include <EEPROM.h>
#include "config.h"

// ===== SENSOR DATA STRUCTURE =====
struct SensorData {
  // BME68X/BSEC data
  float temperature = 0.0;
  float humidity = 0.0;
  float pressure = 0.0;
  float gasResistance = 0.0;
  float iaq = 0.0;
  float staticIaq = 0.0;
  float co2Equivalent = 400.0;
  float breathVocEquivalent = 0.0;
  uint8_t iaqAccuracy = 0;
  uint8_t staticIaqAccuracy = 0;
  uint8_t co2Accuracy = 0;
  uint8_t breathVocAccuracy = 0;
  bool bsecCalibrated = false;
  bool bme68xAvailable = false;
  
  // DS18B20 data
  float externalTemp = 0.0;
  bool ds18b20Available = false;
  
  // PMS5003 data
  uint16_t pm1_0 = 0;
  uint16_t pm2_5 = 0;
  uint16_t pm10 = 0;
  bool pms5003Available = false;
};

// ===== SENSOR STATE MACHINES =====
enum DS18B20State {
  DS18B20_IDLE,
  DS18B20_REQUESTED,
  DS18B20_READING
};

enum PMS5003State {
  PMS5003_SLEEPING,
  PMS5003_WAKING,
  PMS5003_READING,
  PMS5003_RETRY
};

// ===== SENSOR MANAGER CLASS =====
/**
 * @class SensorManager
 * @brief Manages all sensor operations including BME68X, DS18B20, and PMS5003
 * 
 * This class handles initialization, reading, and state management for all sensors.
 * It uses asynchronous state machines for non-blocking sensor operations.
 */
class SensorManager {
private:
  Bsec& bme68x;
  PMS& pms5003;
  PMS::DATA pmsData;

  OneWire oneWire;
  DallasTemperature ds18b20;

  SensorData currentData;
  unsigned long lastSensorRead = 0;
  unsigned long lastStateTime = 0;

  // Sensor corrections
  float tempCorrection = DEFAULT_TEMP_CORRECTION;
  float humidityCorrection = DEFAULT_HUMIDITY_CORRECTION;

  // Async state machines
  DS18B20State ds18State = DS18B20_IDLE;
  unsigned long ds18RequestTime = 0;
  unsigned long lastDS18B20Read = 0;

  PMS5003State pmsState = PMS5003_SLEEPING;
  unsigned long pmsStateTime = 0;
  uint8_t pmsRetryCount = 0;
  uint8_t pmsConsecutiveFailures = 0;
  static const uint8_t PMS_MAX_CONSECUTIVE_FAILURES = 5;

public:
  /**
   * @brief Constructor
   * @param bsec Reference to BSEC sensor instance
   * @param pms Reference to PMS5003 sensor instance
   */
  SensorManager(Bsec& bsec, PMS& pms);
  
  /**
   * @brief Initialize all sensors
   * @return true if at least one sensor initialized successfully
   */
  bool init();
  
  /**
   * @brief Update sensor readings (non-blocking)
   * @return true if new data is available
   */
  bool update();
  
  /**
   * @brief Get current sensor data
   * @return Const reference to current sensor data
   */
  const SensorData& getData() const { return currentData; }
  
  /**
   * @brief Set temperature correction offset
   * @param correction Temperature offset in degrees Celsius
   */
  void setTempCorrection(float correction) { tempCorrection = correction; }
  
  /**
   * @brief Set humidity correction offset
   * @param correction Humidity offset in percent
   */
  void setHumidityCorrection(float correction) { humidityCorrection = correction; }

private:
  bool scanI2CDevice(uint8_t address);
  void scanI2CBus();  // Log all I2C addresses found (for diagnostics)
  bool initBME68X(uint8_t address);
  void configureBsecSensors();
  bool initDS18B20();
  bool initPMS5003();
  
  bool readBME68X();
  bool readDS18B20();
  bool readPMS5003();

  bool saveBsecState();
  bool loadBsecState();
  void resetBsecCalibration();
  void printSensorStatus();
  
  // Validation functions
  bool validateSensorData(const SensorData& data);
  bool isValidTemperature(float temp);
  bool isValidHumidity(float humidity);
  bool isValidPressure(float pressure);
  bool isValidIAQ(float iaq);
  bool isValidCO2(float co2);
  bool isValidVOC(float voc);
  bool isValidPM(uint16_t pm);
};

// ===== IMPLEMENTATION =====
SensorManager::SensorManager(Bsec& bsec, PMS& pms) 
  : bme68x(bsec), pms5003(pms), oneWire(DS18B20_PIN), ds18b20(&oneWire) {}

bool SensorManager::init() {
  DEBUG_INFO("Initializing sensors...");

  // EEPROM for BSEC state (needs 221 bytes minimum) + Config storage (256 bytes)
  if (!EEPROM.begin(1024)) {  // Use 1024 bytes: 512 for BSEC state, 512 for config
    DEBUG_ERROR("EEPROM initialization failed!");
  } else {
    DEBUG_INFO("EEPROM initialized (1024 bytes)");
  }

  bool success = true;

  // Short delay so BME68X can power up (same I2C bus as display)
  delay(150);

  // Initialize BME68X (address 0x76 or 0x77 depending on SDO pin)
  uint8_t bmeAddress = 0;
  if (scanI2CDevice(BME68X_I2C_ADDR_HIGH)) {
    bmeAddress = BME68X_I2C_ADDR_HIGH;
  } else if (scanI2CDevice(BME68X_I2C_ADDR_LOW)) {
    bmeAddress = BME68X_I2C_ADDR_LOW;
  }

  if (bmeAddress != 0) {
    success &= initBME68X(bmeAddress);
  } else {
    DEBUG_ERROR("BME68X not found at 0x%02X or 0x%02X", BME68X_I2C_ADDR_LOW, BME68X_I2C_ADDR_HIGH);
    scanI2CBus();  // Show which I2C devices are present
    currentData.bme68xAvailable = false;
  }
  
  // Initialize DS18B20
  success &= initDS18B20();
  
  // Initialize PMS5003
  success &= initPMS5003();
  
  printSensorStatus();
  return success;
}
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

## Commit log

2025-08-08 Update docs for ESP32 Air Quality Monitor v0.9
    Expanded DATENPUNKTE.md with new sensor management, BSEC configuration, state handling, and exception management for version 0.9. README.md rewritten with detailed hardware, features, installation, data formats, troubleshooting, and project structure for v6.0. Documentation now reflects latest optimizations and robust error handling.
2025-08-17 feat: add structured logging and improved error handling
    [ByteTransmission.h, SensorManager.h, config.h]
2025-08-17 Remove CCS811 sensor from Node-RED flow
2025-08-17 Add Shematics
    [AirQualityMonitor.kicad_pcb, AirQualityMonitor.kicad_sch, untitled.kicad_sch]
2025-08-17 Change Name
    [AirQualityMonitor.kicad_pcb, AirQualityMonitor.kicad_sch, untitled.kicad_sch]
2025-08-20 KiCad Files updated
    [AirQualityMonitor.kicad_sch, untitled.kicad_sch]
2025-08-21 Fix BME680 state loading during initialization
    [AirQualityMonitor.ino, DisplayManager.h, SensorManager.h]
2025-08-23 Fix Node-RED timeout handling and update connection icon
    [AirQualityMonitor.ino, DisplayManager.h]
2025-08-24 Show calibration status star in header
2025-08-24 docs: update pins and add KiCad info
2025-08-31 Fix header collection call and adjust WiFi icon
    [ButtonHandler.h, ByteTransmission.h, DisplayManager.h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]
2025-08-31 Add Pictures
    [Deckel.stl, Diffusor.stl, Gehäuse.stl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]
2025-08-31 Update README with printables link and description
2025-11-15 fix: resolve critical performance and security issues
    This commit addresses 10 critical code quality issues identified in the code review:
    CRITICAL FIXES:
    1. Problem 2: Fixed TimeUtils.h initialization bug that caused incorrect uptime on first call
    2. Problem 6: Changed saveBsecState() and loadBsecState() to return bool for proper error handling
    3. Problem 3: Fixed BSEC state race condition - only update lastStateTime on successful save
    4. Problem 4: Added comprehensive buffer overflow protection in BSEC state save/load
    5. Problem 5: Fixed potential deadlock in ButtonHandler ISR by protecting millis() call
    6. Problem 7: Added sensor availability validation in AQI calculation
    7. Problem 8: R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
    [AirQualityMonitor.ino, ButtonHandler.h, ByteTransmission.h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]
2025-11-15 fix: resolve BSEC CO2/VOC zero values issue (v1.1.0)
    BSEC CO2 equivalent and VOC equivalent values were stuck at zero
    even after 1+ hour of operation. Root cause: BSEC ULP mode does not
    provide reliable CO2/VOC equivalent outputs.
    Changes:
    - Switch BSEC from ULP mode to LP mode (3s sampling interval)
    - Update version to 1.1.0 in main sketch
    - Update README with version history and changelog
    - Add technical details about the fix
    Technical details:
    - BSEC_SAMPLE_RATE_ULP → BSEC_SAMPLE_RATE_LP
    - Power consumption: ~0.1mA → ~0.3mA (acceptable tradeoff)
    - All BSEC outputs (IAQ, CO2, VOC, temp, humidity) now work reliably
    Fixes: CO2 and VOC values returning 0 with accuracy 0
    [AirQualityMonitor.ino, SensorManager.h]
2025-11-15 fix: improve BSEC sensor initialization and add comprehensive debugging
    This commit addresses potential issues with BSEC sensor reading and initialization:
    Changes to SensorManager.h:
    - Fixed redundant bme68x.run() call in readBME68X()
    - Added error handling for BSEC errors in update loop
    - Improved EEPROM initialization (512 bytes instead of dynamic size)
    - Enhanced debug output during BME68X initialization
    - Added detailed status checks after each initialization step
    - Made BSEC state loading non-critical (won't fail init)
    - Added debug output for first sensor readings
    Changes to AirQualityMonitor.ino:
    - Added comprehensive sensor data debug output in loop()
    - Debug shows first 10 readin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
    [AirQualityMonitor.ino, SensorManager.h]
2025-11-15 fix: add BSEC calibration reset for ULP->LP mode change
    The old BSEC calibration state saved in ULP mode is incompatible
    with the new LP mode, causing accuracy to stay at 0 indefinitely.
    - Added resetBsecCalibration() function to clear EEPROM
    - Function is ACTIVE by default to reset incompatible state
    - Detailed calibration timeline in debug output
    - Updated README with LP mode calibration times
    - Added instructions to comment out reset after first run
    Calibration timeline (LP mode):
    - 0-5 min: accuracy = 0 (warming up)
    - 5-20 min: accuracy = 1 (initial calibration)
    - 20+ min: accuracy = 2-3 (fully calibrated)
    IMPORTANT: After first successful run with accuracy > 0,
    comment out l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
    [SensorManager.h]
2025-12-22 feat: integrate MQTT functionality for data publishing
    This commit introduces MQTT support to the Air Quality Monitor, allowing for real-time data publishing. Key changes include:
    - Added MQTTManager class for handling MQTT connections and data publishing.
    - Updated setup() to initialize and connect to the MQTT broker.
    - Enhanced loop() to publish sensor data to MQTT alongside Node-RED.
    - Configured MQTT settings in config.h and secrets_template.h for user customization.
    This integration aims to improve data accessibility and facilitate Home Assistant integration.
    [AirQualityMonitor.ino, config.h]
2025-12-22 refactor: enhance sensor data validation and improve thread safety
    This commit introduces several improvements to the sensor management and data handling processes:
    - Added validation functions for temperature, humidity, pressure, IAQ, CO2, VOC, and PM values to ensure data integrity.
    - Implemented error handling for invalid sensor readings, logging warnings when values fall outside expected ranges.
    - Enhanced the `getUptimeMillis()` function with thread safety using critical sections to prevent race conditions.
    - Updated the `SensorManager` class to utilize these validation functions during sensor data updates, ensuring only valid data is processed.
    - Improved the `ByteTransmissionManager`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
    [ButtonHandler.h, ByteTransmission.h, DisplayManager.h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]
2025-12-22 refactor: simplify display buffer handling and update MQTTManager method signatures
    This commit refactors the DisplayManager and MQTTManager classes to improve code clarity and functionality:
    - Updated the `showMessage` method in DisplayManager to remove error checking for `sendBuffer()`, as it returns void.
    - Modified the `publishSensorDiscovery` and `publishAvailability` methods in MQTTManager to remove the `const` qualifier, allowing for more flexible method implementations.
    These changes aim to streamline the display handling process and enhance the MQTTManager's method usability.
    [DisplayManager.h]
2025-12-22 feat: update Air Quality Monitor to version 1.2 with internal calculations
    This commit introduces significant enhancements to the Air Quality Monitor, including:
    - Removed Node-RED dependency, with all calculations now performed internally.
    - Updated versioning to 1.2.0 and improved memory optimization.
    - Introduced LED color transition effects for smoother visual feedback.
    - Refactored DisplayManager and LEDManager to streamline display updates and LED handling.
    - Enhanced MQTTManager to publish additional calculated values and improve data structure.
    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
2025-12-23 Update README.md for version 1.5.1, highlighting new MQTT Home Assistant integration, internal AQI calculations, and improved sensor data handling. Added detailed changelog and fixed JSON field names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
2025-12-23 Update Air Quality Monitor to version 1.5.1, introducing bug fixes and stability improvements. Enhanced configuration management with EEPROM support for storing settings, added Arduino OTA functional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
    [AirQualityMonitor.ino, SensorManager.h, config.h]
2025-12-25 Enhance MQTTManager with binary sensor discovery and status management
    This update introduces new methods for publishing binary sensor discovery configurations and improves status management by adding a dedicated status topic. The MQTT connection now includes Last Will 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
2026-02-01 Refactor WiFi connection handling and enhance MQTT discovery publishing
    This update improves the WiFi connection management by ensuring automatic reconnection attempts every 30 seconds if the connection is lost. It also enhances the MQTTManager by adding checks for MQTT 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
2026-04-10 fix: stabilize MQTT discovery and add BME68X I2C diagnostics
    - Defer MQTT discovery to update() with 2s stabilization delay after connect
    - Add DISCOVERY_CHECK_CONNECTED() macro to abort discovery mid-run on disconnect
    - Add 60s backoff retry for aborted discovery runs (nextDiscoveryRetryAt)
    - Avoid resetting discoveryPublished on reconnect to prevent 2s online/offline loop
    - Add delay(100) + mqttClient.loop() after each discovery publish for broker stability
    - Add scanI2CBus() in SensorManager for full I2C bus scan when BME68X not found
    - Add 150ms power-up delay before BME68X init (shared I2C bus with display)
    - Define BME68X_I2C_ADDR_LOW/HIGH constants with #ifndef guards in config.h
    - Fi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
    [AirQualityMonitor.ino, SensorManager.h, config.h]
2026-04-10 fix: close rapid-reconnect loop and add disconnect diagnostics
    Three bugs fixed:
    1. lastReconnectAttempt = 0 in reconnect() bypassed the 5-second throttle,
    causing immediate re-attempt on every drop → tight loop.
    2. hasEverConnected guard prevented discovery from being rescheduled after
    any reconnect, so discovery was never retried when first attempt failed.
    3. No state code logged when connection dropped after CONNACK, making root
    cause of broker-side disconnect invisible.
    - Remove lastReconnectAttempt = 0 in reconnect(); throttle now always enforced
    - Remove hasEverConnected flag entirely; guard discovery scheduling with
    !discoveryRequestedAfterConnect to avoid dupli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
2026-04-10 fix: speed up discovery to beat short broker connection window
    Broker (192.168.178.36:403, cross-subnet) closes TCP within 76-1354ms
    (PubSubClient state -3). Previous timings made discovery impossible:
    - 2000ms stabilization delay → discovery timer never fired
    - 100ms per-sensor delay → 30 sensors = 3s total, far too long
    Fixes:
    - Reduce stabilization delay: 2000ms → 500ms
    - Reduce per-publish delay: 100ms → 10ms (30 sensors now ~300ms total)
    - Subscribe to baseTopic/cmd/# after connecting to give the broker an
    active bidirectional session, reducing likelihood of idle-timeout drops
2026-04-10 fix: unique MQTT client ID per device via hostname, fix MAC before WiFi-init
    Both ESP32 boards produced identical client IDs (AirQualityMonitor_5c3ffc3f9301),
    causing Mosquitto to disconnect them alternately every 5 s in an endless loop.
    Root causes:
    1. getMacAddress() called in MQTTManager constructor before WiFi.begin(),
    returning garbage/identical values on some boards.
    2. Even with correct MACs: cloned or identically-flashed boards share the
    same hardware MAC, leading to duplicate client IDs.
    Fix:
    - Use hostname (from ConfigManager EEPROM) as primary client ID component.
    Each device has its own hostname (ENV-Wohn_Dennis, ENV-Bad, etc.).
    - Re-read MAC in init() after WiFi is ini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
2026-04-10 Fix MQTT discovery MAC mismatch and add diagnostics
    MQTTManager.h: discoveryPrefix and binarySensorDiscoveryPrefix were set
    in the constructor before WiFi driver init. WiFi.macAddress() returned
    garbage bytes at that point, creating a topic/payload MAC mismatch that
    caused HA to silently drop all discovery messages. Fixed by recomputing
    both prefixes in init() after re-reading the MAC with WiFi active.
    Also improved discovery stability:
    - DISCOVERY_CHECK_CONNECTED() macro aborts mid-run if broker drops
    - 60 s backoff retry when discovery was aborted
    - 500 ms stabilization delay before first publish (was 2 s)
    - reconnect() resets discoveryPublished to force republish after reconnect
    (resto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
    [AirQualityMonitor.ino, SensorManager.h]
2026-04-10 fix: always publish all sensor fields to avoid HA template warnings
    When PMS5003, DS18B20, or BME68X is offline, the corresponding JSON
    fields were omitted from the state payload. HA's value_templates then
    logged 'dict object has no attribute X' warnings every publish cycle.
    Now all registered fields are always present: 0 / 0.0 when the sensor
    is unavailable. The sensor_pmsXXX_available / sensor_bme68x_available
    flags already signal the offline state to automations.
2026-04-10 Remove aqi_color_code entity from MQTT discovery and state
    Hex color strings published as sensor values caused HA to display a
    rainbow color-bar in the state history with no useful information.
    Removed publishSensorDiscovery call and doc["aqi_color_code"] from
    publishData(). Cleared retained discovery topics from both MQTT-Dennis
    and MQTT_Haus so HA removes the entity automatically.
2026-04-11 feat: v1.5.5 - sensible MQTT decimal precision, improved entity naming
    - Round float values in publishData() to sensible precision:
    temperature/external_temperature: 2dp, humidity: 1dp, pressure: 1dp,
    iaq/static_iaq/co2/gas_resistance: 0dp (integer), voc/tvoc_mgm3: 2dp,
    dew_point/heat_index: 1dp, absolute_humidity: 2dp, aqi_index: 1dp
    - MQTT Discovery: use bare field name + has_entity_name=true + object_id
    to eliminate double-prefix entity_ids in Home Assistant
    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
2026-04-11 docs: update README, DATENPUNKTE and CLAUDE.md for v1.5.5
    - README: correct version, state topic, full JSON example with all 40+
    fields and rounded decimals, entity list, updated version table
    - DATENPUNKTE: rewrite for current firmware (remove binary protocol and
    Node-RED references, add all calculated/alert/system fields, LP mode)
    - CLAUDE.md: add Arduino IDE board settings table with partition note
2026-04-11 feat: v1.5.6 - stealth button countdown + MQTT baseTopic fix
    Two changes shipped together because both were needed for a clean
    multi-board flash to work:
    1. Stealth-mode button countdown (user-facing)
    - Shows a 3-2-1 overlay on the OLED while holding the select button
    - Fires the stealth toggle at 3s while still held (no more waiting
    for release and hoping you held long enough)
    - Short click still switches the view; countdown only shows after
    300 ms of hold to avoid flicker on quick clicks
    - BUTTON_LONG_PRESS_MS: 2000 -> 3000 ms
    - DisplayManager caches the last rendered frame so the normal view
    snaps back immediately on release
    2. MQTTManager baseTopic bug fix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
    [ButtonHandler.h, DisplayManager.h, config.h]
